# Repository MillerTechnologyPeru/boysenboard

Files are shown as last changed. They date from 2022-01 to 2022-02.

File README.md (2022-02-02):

# BoysenBoard
Linux capable single board computer using the F1C200s in an Arduino form-factor.

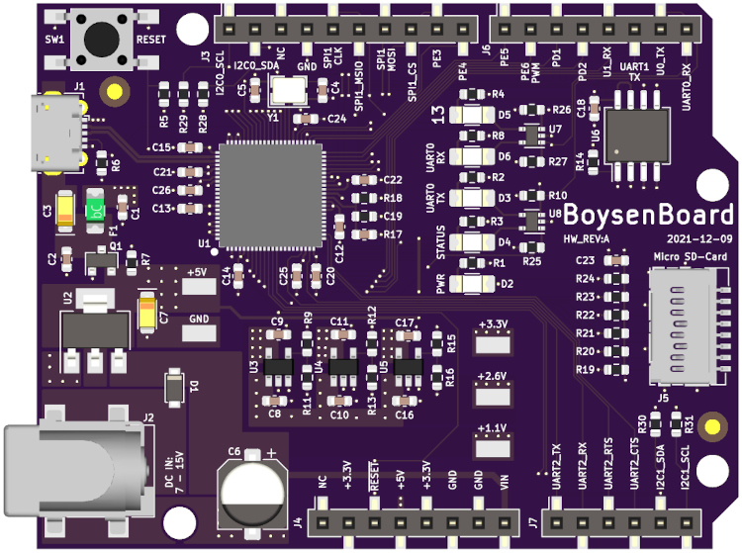
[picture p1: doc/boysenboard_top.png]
BoysenBoard Top


## Build
The BoysenBoard supports booting from the on-board 16MB of SPI flash or from a 
Micro-SD card. The board will first try to boot from the SD card. If that 
fails, it will try the SPI flash. Otherwise it will enter FEL bootloader mode. 

### Setting up the Buildroot Environment
Clone this repo:
```
git clone https://github.com/mclewell/boysenboard
git submodule update --init
```
Change to the Buildroot directory:
```
cd boysenboard/software/buildroot
```

### Building the SPI Flash Image
We will be doing an out-of-tree build. Make an directory for the output:
```
mkdir output-spi
cd output-spi
```
Set-up the build:
```
make -C ../ O=$(pwd) BR2_EXTERNAL=$PWD/../../ boysenboard_spi_defconfig
```
Start the build (on my Ryzen 3900X this took about 7mins):
```
make
```
Once complete, the resulting flash image will be at:
```
images/flash.bin
```
To flash images into the SPI flash, the board must be in FEL mode. If the SPI 
flash is blank, the board will automatically enter FEL mode. If a valid boot 
image already exists in the flash, the board can be placed into FEL mode using
a special SD-Card image.
```
wget https://github.com/linux-sunxi/sunxi-tools/raw/master/bin/fel-sdboot.sunxi
dd if=fel-sdboot.sunxi of=/dev/sdX bs=1024 seek=8
```
Note: ensure the board is fully powered down. Sometimes external USB-UART cables
will back-power the board.

Insert the FEL SD-Card and connect the USB cable. FEL mode can be verified by 
using ```lsusb```:
```
Bus 005 Device 010: ID 1f3a:efe8 Allwinner Technology sunxi SoC OTG connector in FEL/flashing mode
```
Start the flashing process with:
```
sudo host/bin/sunxi-fel -p spiflash-write 0 images/flash.bin
```
This process will take about 3mins. Once complete, remove the USB cable and 
SD-Card. Connect to the serial console on UART0 to see console output messages.

The first boot after flashing a new image will take a while as U-Boot sets up 
the UBIFS. Subsequent boots will be much fast. You will see the following 
messages from U-Boot while this occurs:
```
...
SF: Detected w25q128 with page size 256 Bytes, erase size 64 KiB, total 16 MiB
ubi0: attaching mtd2
ubi0: scanning is finished
ubi0: attached mtd2 (name "rootubi", size 15 MiB)
ubi0: PEB size: 65536 bytes (64 KiB), LEB size: 65408 bytes
ubi0: min./max. I/O unit sizes: 1/256, sub-page size 1
ubi0: VID header offset: 64 (aligned 64), data offset: 128
ubi0: good PEBs: 252, bad PEBs: 0, corrupted PEBs: 0
ubi0: user volume: 5, internal volumes: 1, max. volumes count: 128
ubi0: max/mean erase counter: 0/0, WL threshold: 4096, image sequence number: 1562368489
ubi0: available PEBs: 12, total reserved PEBs: 240, PEBs reserved for bad PEB handling: 0
...
```

Once booted, the login information is:
```
User: root
Password: [none]
```
The SPI flash image also sets the board up as a USB Gadget presenting the host
computer with a serial COM port device and USB mass storage. The serial port
typically enumerates as /dev/ttyACM0. 

### Building the SD Card Image
Like the SPI image,  we will be doing an out-of-tree build. Make an directory 
for the output:
```
mkdir output-sd
cd output-sd
```
Set-up the build:
```
make -C ../ O=$(pwd) BR2_EXTERNAL=$PWD/../../ boysenboard_sd_defconfig
```
Start the build (on my Ryzen 3900X this took about 7mins):
```
make
```
Once complete, the resulting SD-Card image will be at:
```
images/sdcard.img
```
Write the image to an SD-Card:
```
sudo dd if=image/sdcard.img of=/dev/sdX bs=1M status=progress && sync
```
Note: the SD-Card image does not enable the USB Gadget feature.

# Acknowledgements
This project is derived from [George Hillard's busiesscard-linux](https://github.com/thirtythreeforty/businesscard-linux)
project. 

Also thanks to [Icenowy](https://github.com/Icenowy) for their work getting U-Boot and Linux running
on the F1C100s and F1C200s processors.

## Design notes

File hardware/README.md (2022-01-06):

# Known Issues
- Silk swapped for R17 and C19
- Alignment holes for J1 are too small
- Add paste aperatures for SD-Card socket (J5)
- Add paste aperatures for GND hole pads on USB connector (J1)
- Add buffers on UART0 (my external tools are back-powering through the F1C200s 
ESD diodes)
- Remove UART0 RX/TX from LEDs and replace with other GPIO (LEDs are always on 
and 115200 baud is too fast for any meaningful blinking)
- Button or jumper to enter FEL Mode by holding SPI0_CS low.

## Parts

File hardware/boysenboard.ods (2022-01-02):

# | References | Value | QTY | Manufacturer | PartNumber | Supplier | SupplierPartNumber
1 | C4 C5 | 30pF | 2 | YAGEO | CC0603JRNPO9BN300 | Digi-Key | 311-3357-1-ND
2 | C1 C2 C13 C14 C15 C18 C19 C21 C22 C23 C25 C26 | 0.1uF | 12 | Samsung Electro-Mechanics | CL10B104KB8NNNL | Digi-Key | 1276-CL10B104KB8NNNLCT-ND
3 | C8 C9 C10 C11 C12 C16 C17 C20 C24 | 1uF | 9 | Samsung Electro-Mechanics | CL10B105KA8NFNC | Digi-Key | 1276-1942-1-ND
4 | C3 C7 | 10uF | 2 | KYOCERA AVX | TAJA106K016SNJ | Digi-Key | 478-8875-1-ND
5 | C6 | 47uF | 1 | Wurth Elektronik | 875105344006 | Digi-Key | 732-6421-1-ND
6 | D1 | DSS16UTR | 1 | SMC Diode Solutions | DSS16UTR | Digi-Key | 1655-1929-1-ND
7 | D2 D3 D4 D5 D6 | GRN | 5 | Wurth Elektronik | 150120VS75000 | Digi-Key | 732-4993-1-ND
8 | F1 | 500mA | 1 | Eaton - Electronics Division | PTS120615V050 | Digi-Key | 283-3140-1-ND
9 | J1 | 1050171001 | 1 | Molex | 1050171001 | Digi-Key | WM11262CT-ND
10 | J2 | 54-00164 | 1 | Tensility International Corp | 54-00164 | Digi-Key | 839-54-00164CT-ND
11 | J5 | Micro-SD | 1 | Molex | 1051620001 | Digi-Key | WM14405CT-ND
12 | J7 | NPTC061KFXC-RC | 1 | Sullins Connector Solutions | NPTC061KFXC-RC | Digi-Key | S5598-ND
13 | J4 J6 | NPTC081KFXC-RC | 2 | Sullins Connector Solutions | NPTC081KFXC-RC | Digi-Key | S5600-ND
14 | J3 | NPTC101KFXC-RC | 1 | Sullins Connector Solutions | NPTC101KFXC-RC | Digi-Key | S5602-ND
15 | Q1 | BSS308PEH6327XTSA1 | 1 | Infineon Technologies | BSS308PEH6327XTSA1 | Digi-Key | BSS308PEH6327XTSA1CT-ND
16 | R2 R3 R4 R8 | 261 | 4 | Stackpole Electronics Inc | RMCF0603FT261R | Digi-Key | RMCF0603FT261RTR-ND
17 | R1 | 604 | 1 | Stackpole Electronics Inc | RMCF0603FT604R | Digi-Key | RMCF0603FT604RCT-ND
18 | R17 R18 | 2.2K | 2 | Stackpole Electronics Inc | RMCF0603FT2K20 | Digi-Key | RMCF0603FT2K20CT-ND‎
19 | R28 R29 R30 R31 | 4.7K | 4 | Stackpole Electronics Inc | RMCF0603FT4K70 | Digi-Key | RMCF0603FT4K70DKR-ND
20 | R7 R14 R19 R20 R21 R22 R23 R24 | 10K | 8 | Stackpole Electronics Inc | RMCF0603FT10K0 | Digi-Key | RMCF0603FT10K0TR-ND
21 | R9 | 17.8K | 1 | Stackpole Electronics Inc | RMCF0603FG17K8 | Digi-Key | RMCF0603FG17K8CT-ND
22 | R5 R6 R10 R11 R13 R16 R25 R26 R27 | 47K | 9 | Stackpole Electronics Inc | RMCF0603FT47K0 | Digi-Key | RMCF0603FT47K0TR-ND
23 | R12 | 105K | 1 | Stackpole Electronics Inc | RMCF0603FT105K | Digi-Key | RMCF0603FT105KCT-ND
24 | R15 | 147K | 1 | Stackpole Electronics Inc | RMCF0603FT147K | Digi-Key | RMCF0603FT147KCT-ND
25 | SW1 | PTS645SL70SMTR92LFS | 1 | C&K | PTS645SL70SMTR92LFS | Digi-Key | CKN10820CT-ND
26 | U3 U4 U5 | AP7366-W5-7 | 3 | Diodes Incorporated | AP7366-W5-7 | Digi-Key | AP7366-W5-7DICT-ND
27 | U7 U8 | DMN32D2LDF | 2 | Diodes Incorporated | DMN32D2LDF-7 | Digi-Key | DMN32D2LDF-7DICT-ND
28 | U1 | F1C200s | 1 | Allwinner | F1C200s | SuperBuy | F1C200s
29 | U2 | LM1117-5.0 | 1 | Texas Instruments | LM1117MPX-5.0 | Digi-Key | LM1117MPX-5.0CT-ND
30 | U6 | W25Q128JVSIQ | 1 | Winbond Electronics | W25Q128JVSIQ | Digi-Key | W25Q128JVSIQ-ND
31 | Y1 | 24MHz | 1 | ECS Inc. | ECS-240-20-33-TR3 | Digi-Key | 50-ECS-240-20-33-TR3CT-ND

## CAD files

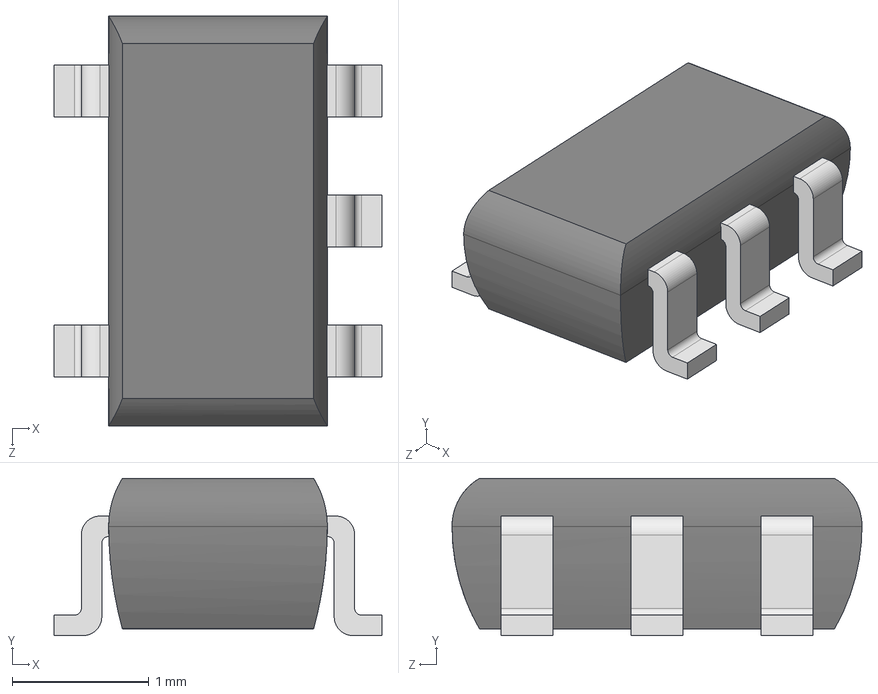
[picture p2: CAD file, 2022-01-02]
hardware/models/User Library-sot25.step
2.40 x 1.15 x 3.00 mm

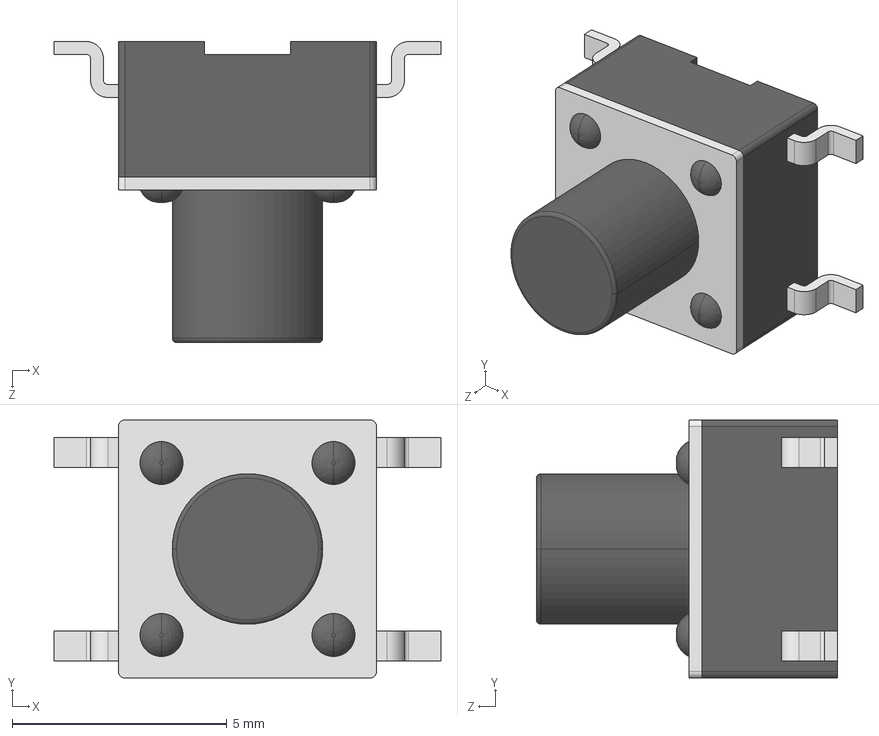
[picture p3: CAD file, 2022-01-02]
hardware/models/User Library-PTS645SL70SMTR92-LFS.STEP
9.00 x 6.00 x 7.00 mm

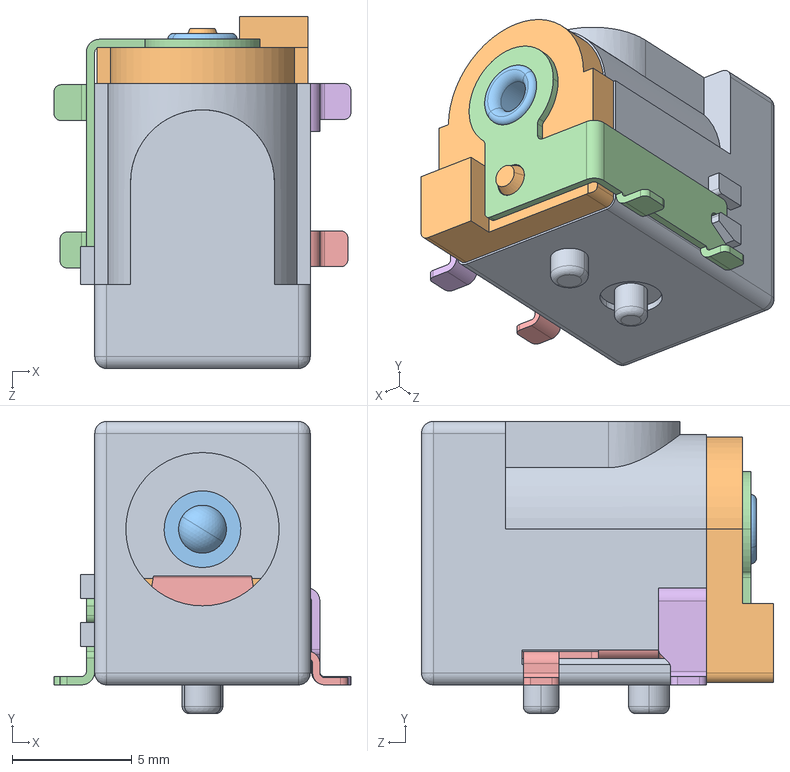
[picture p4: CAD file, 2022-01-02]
hardware/models/54-00164.STEP
12.4 x 12.2 x 14.7 mm
54-00164_shell
54-00164_insulator
54-00164_center
54-00164_center contact
54-00164_spring contact
54-00164_shell contact

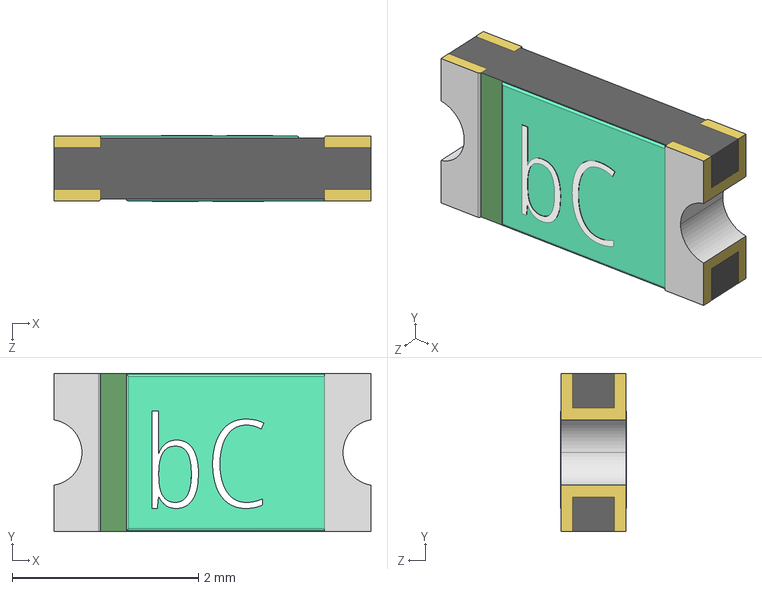
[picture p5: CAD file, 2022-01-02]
hardware/models/User Library-0ZCJ0005FF2E.step
3.40 x 1.70 x 0.708 mm

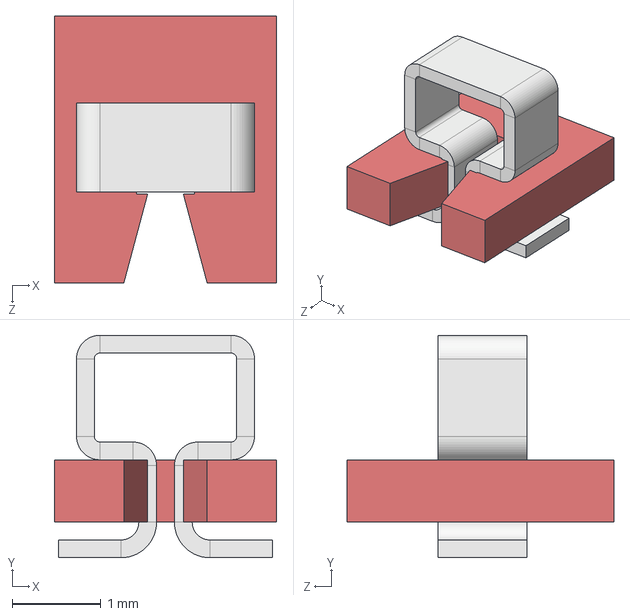
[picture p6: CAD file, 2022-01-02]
hardware/models/keystone-PN5190TR.STEP
2.50 x 2.50 x 3.00 mm
5190_insulation
5190_assembled contact

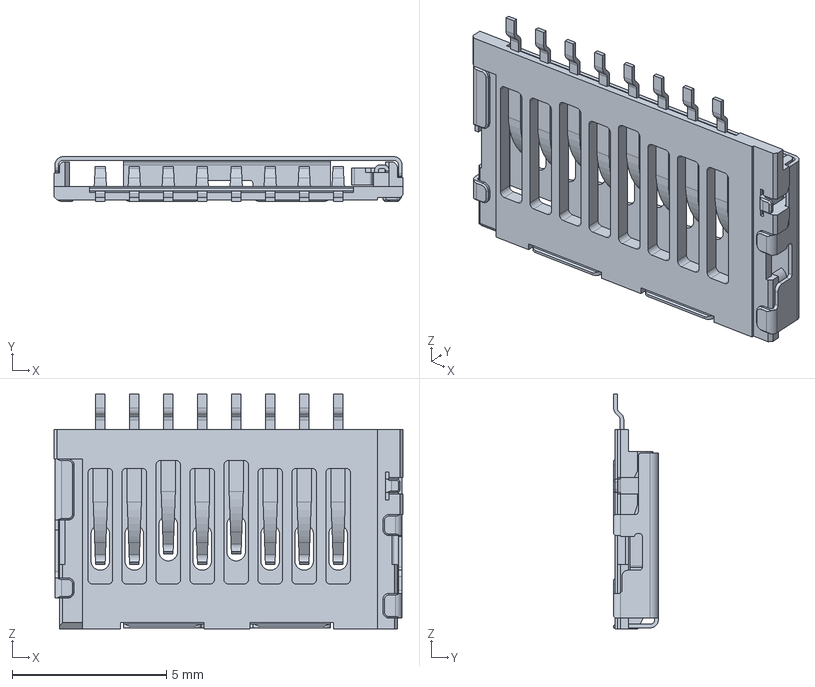
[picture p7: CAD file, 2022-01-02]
hardware/models/1051620001.stp
11.3 x 1.45 x 7.60 mm

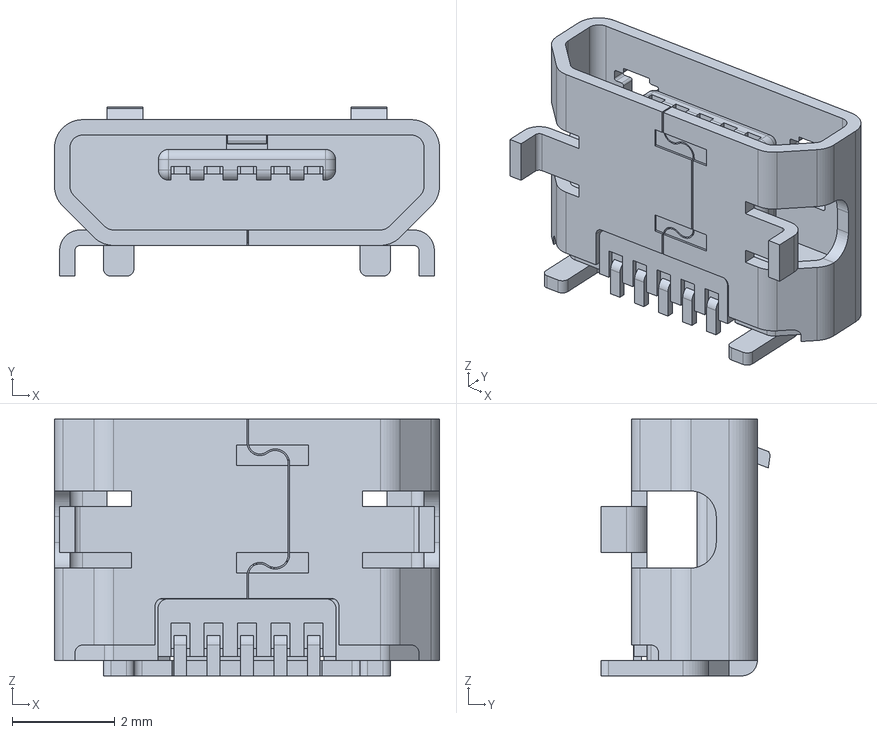
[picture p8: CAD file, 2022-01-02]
hardware/models/1050171001.stp
7.50 x 3.30 x 5.00 mm

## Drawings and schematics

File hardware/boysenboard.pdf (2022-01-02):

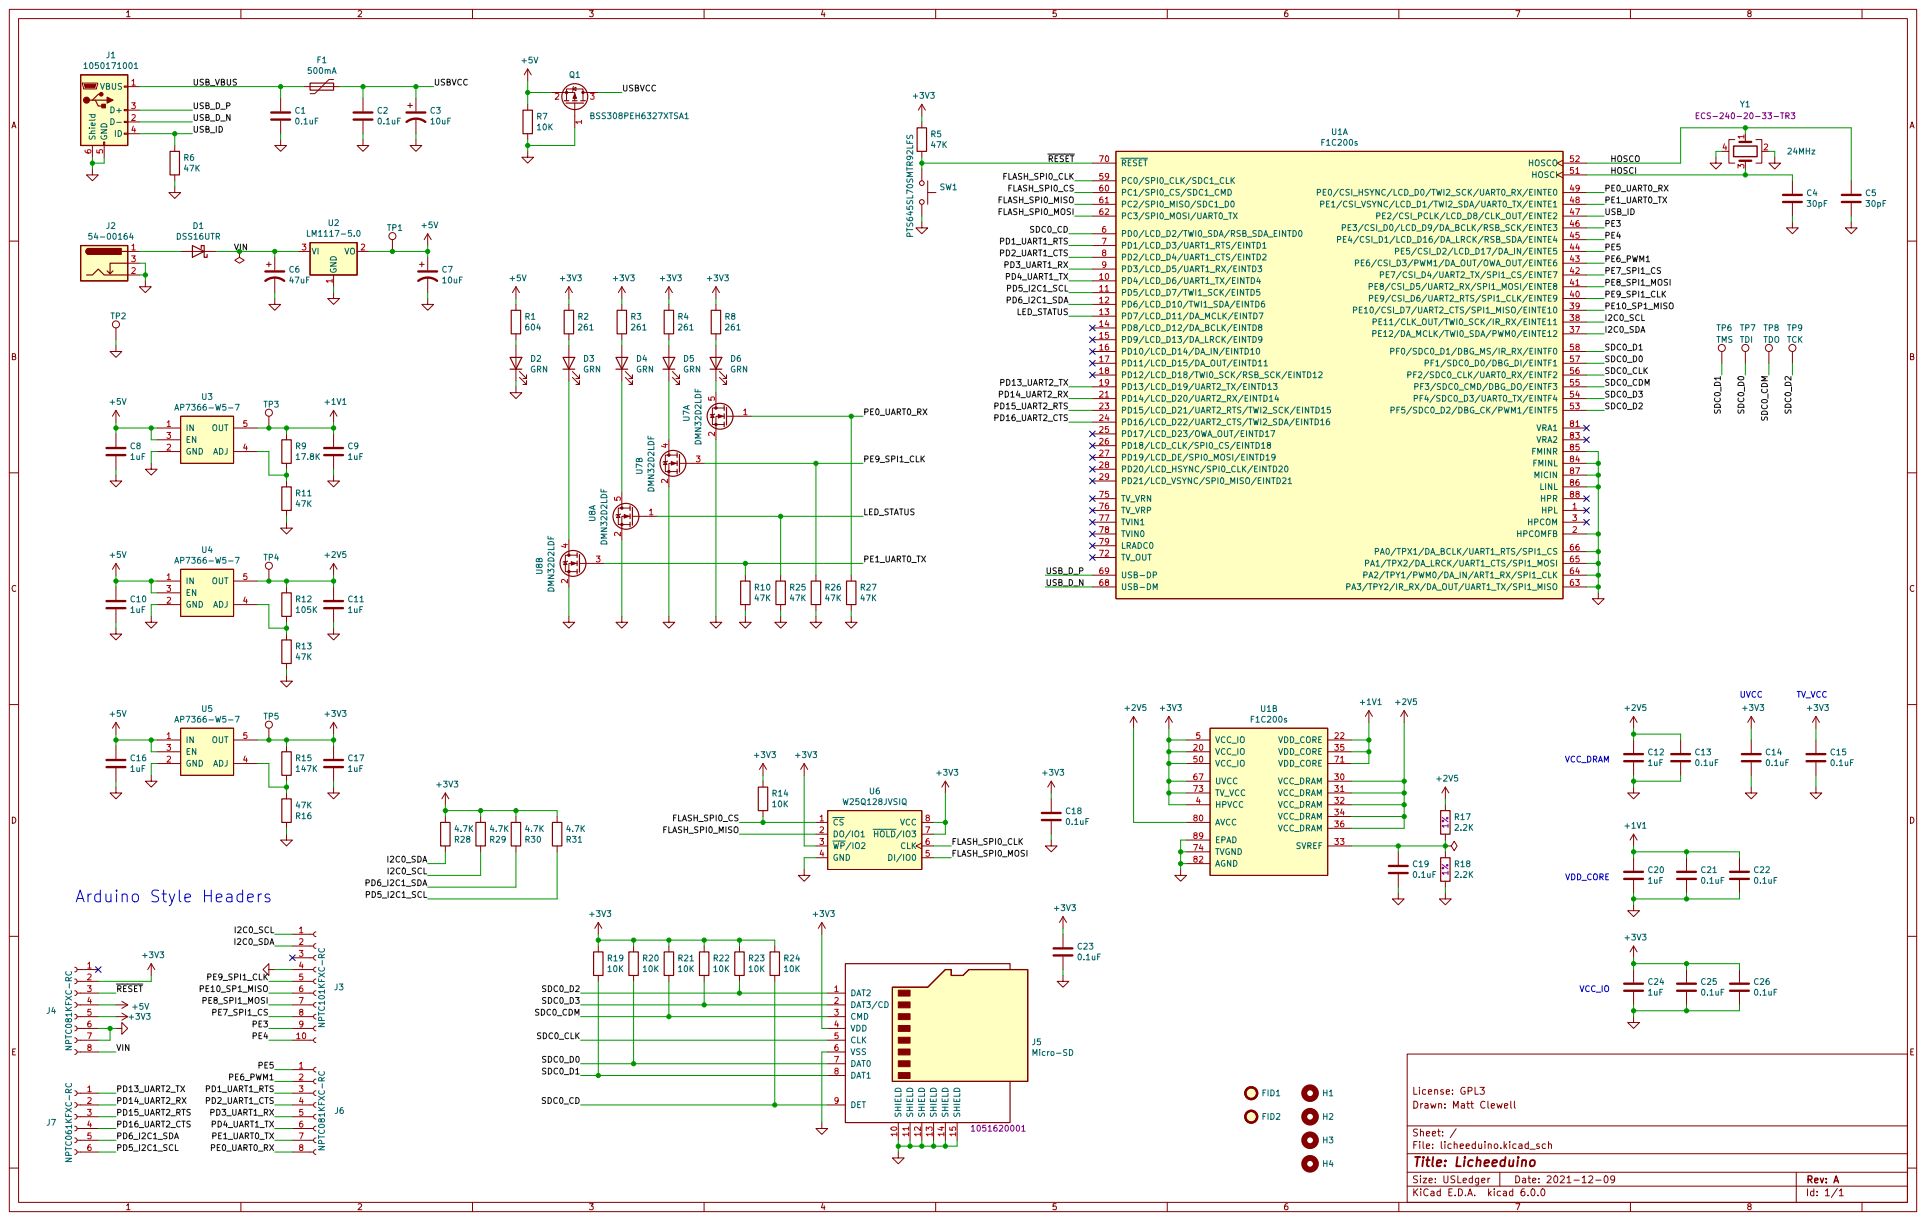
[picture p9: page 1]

File: licheeduino.kicad_sch Sheet: / Drawn: Matt Clewell License: GPL3

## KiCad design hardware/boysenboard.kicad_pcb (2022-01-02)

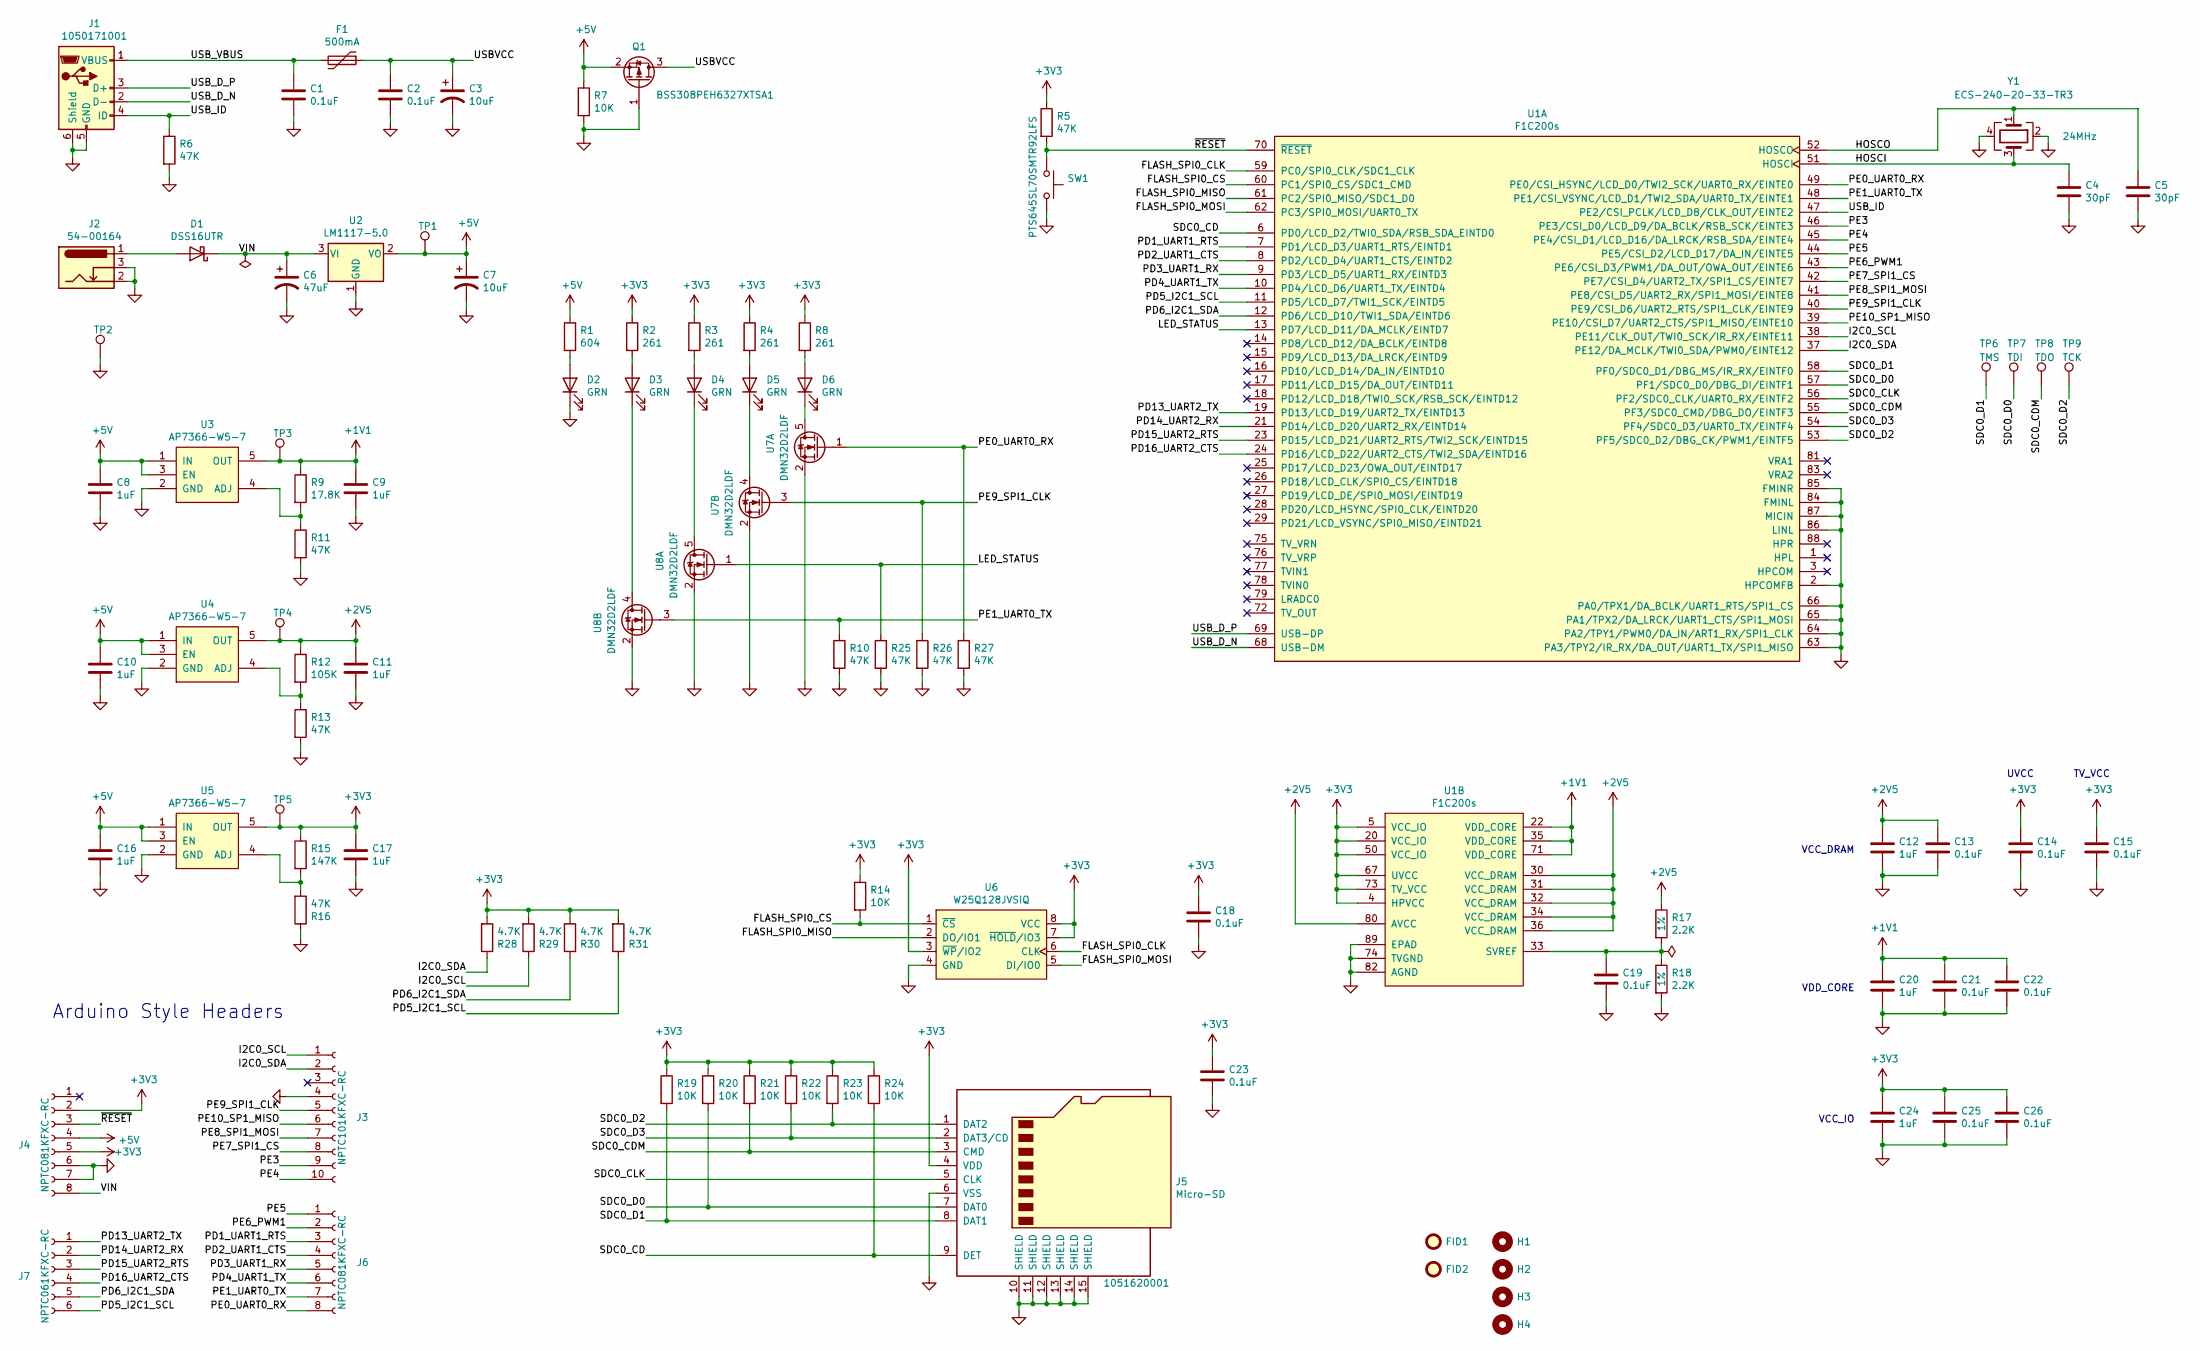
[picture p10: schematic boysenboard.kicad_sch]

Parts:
C1, C2, C13, C14, C15, C18, C19, C21, C22, C23, C25, C26: 0.1uF; C_0603_1608Metric; PartNumber CL10B104KB8NNNL
C3, C7: 10uF; CP_EIA-3216-18_Kemet-A; PartNumber TAJA106K016SNJ
C4, C5: 30pF; C_0603_1608Metric; PartNumber CC0603JRNPO9BN300
C6: 47uF; CP_Elec_6.3x5.8; PartNumber 875105344006
C8, C9, C10, C11, C12, C16, C17, C20, C24: 1uF; C_0603_1608Metric; PartNumber CL10B105KA8NFNC
D1: DSS16UTR; D_SOD-123F; PartNumber DSS16UTR
D2, D3, D4, D5, D6: GRN; LED_1206_3216Metric_Castellated; PartNumber 150120VS75000
F1: 500mA; Fuse_1206_3216Metric_Castellated; PartNumber PTS120615V050
FID1, FID2: Fiducial; Fiducial_1.5mm_Mask3mm
H1, H2, H3, H4: MountingHole; mounting_hole_125mil
J1: 1050171001; USB_Micro-B_Molex-105017-0001; PartNumber 1050171001
J2: 54-00164; barrel_jack_2.1mm; PartNumber 54-00164
J3: NPTC101KFXC-RC; PinSocket_1x10_P2.54mm_Vertical_SMD_Pin1Right; PartNumber NPTC101KFXC-RC
J4, J6: NPTC081KFXC-RC; PinSocket_1x08_P2.54mm_Vertical_SMD_Pin1Right; PartNumber NPTC081KFXC-RC
J5: Micro-SD; micro-sd; PartNumber 1051620001
J7: NPTC061KFXC-RC; PinSocket_1x06_P2.54mm_Vertical_SMD_Pin1Right; PartNumber NPTC061KFXC-RC
Q1: BSS308PEH6327XTSA1; SOT-23; PartNumber BSS308PEH6327XTSA1
R1: 604; R_0603_1608Metric; PartNumber RMCF0603FT604R
R2, R3, R4, R8: 261; R_0603_1608Metric; PartNumber RMCF0603FT261R
R5, R6, R10, R11, R13, R16, R25, R26, R27: 47K; R_0603_1608Metric; PartNumber RMCF0603FT47K0
R7, R14, R19, R20, R21, R22, R23, R24: 10K; R_0603_1608Metric; PartNumber RMCF0603FT10K0
R9: 17.8K; R_0603_1608Metric; PartNumber RMCF0603FG17K8
R12: 105K; R_0603_1608Metric; PartNumber RMCF0603FT105K
R15: 147K; R_0603_1608Metric; PartNumber RMCF0603FT147K
R17, R18: 2.2K; R_0603_1608Metric; Tolerance 1%; PartNumber RMCF0603FT2K20
R28, R29, R30, R31: 4.7K; R_0603_1608Metric; PartNumber RMCF0603FT4K70
SW1: PTS645SL70SMTR92LFS; switch_tactile_6x6mm_smt; PartNumber PTS645SL70SMTR92LFS
TP1, TP2, TP3, TP4, TP5: TestPoint; test_point_RCSCTE
TP6: TMS; TestPoint_Pad_D1.0mm
TP7: TDI; TestPoint_Pad_D1.0mm
TP8: TDO; TestPoint_Pad_D1.0mm
TP9: TCK; TestPoint_Pad_D1.0mm
U1: F1C200s; QFN-88; PartNumber F1C200s
U2: LM1117-5.0; SOT-223-3_TabPin2; PartNumber LM1117MPX-5.0
U3, U4, U5: AP7366-W5-7; SOT-23-6; PartNumber AP7366-W5-7
U6: W25Q128JVSIQ; SO-8_5.3x6.2mm_P1.27mm; PartNumber W25Q128JVSIQ
U7, U8: DMN32D2LDF; SOT-353_SC-70-5; PartNumber DMN32D2LDF-7
Y1: 24MHz; Crystal_SMD_Abracon_ABM8G-4Pin_3.2x2.5mm; PartNumber ECS-240-20-33-TR3

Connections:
+1V1: C9.1, C20.1, C21.1, C22.1, R9.1, TP3.1, U1.22 (VDD_CORE), U1.35 (VDD_CORE), U1.71 (VDD_CORE), U3.5 (OUT)
+2V5: C11.1, C12.1, C13.1, R12.1, R17.1, TP4.1, U1.30 (VCC_DRAM), U1.31 (VCC_DRAM), U1.32 (VCC_DRAM), U1.34 (VCC_DRAM), U1.36 (VCC_DRAM), U1.80 (AVCC), U4.5 (OUT)
+3V3: C14.1, C15.1, C17.1, C18.1, C23.1, C24.1, C25.1, C26.1, J4.2, J4.5, J5.4 (VDD), R2.1, R3.1, R4.1, R5.1, R8.1, R14.1, R15.1, R19.1, R20.1, R21.1, R22.1, R23.1, R24.1, R28.2, R29.2, R30.2, R31.2, TP5.1, U1.4 (HPVCC), U1.5 (VCC_IO), U1.20 (VCC_IO), U1.50 (VCC_IO), U1.67 (UVCC), U1.73 (TV_VCC), U5.5 (OUT), U6.3 (~WP/IO2), U6.7 (~HOLD/IO3), U6.8 (VCC)
+5V: C7.1, C8.1, C10.1, C16.1, J4.4, Q1.2 (S), R1.1, R7.1, TP1.1, U2.2 (VO), U3.1 (IN), U3.3 (EN), U4.1 (IN), U4.3 (EN), U5.1 (IN), U5.3 (EN)
/FLASH_SPI0_CLK: U1.59 (PC0/SPI0_CLK/SDC1_CLK), U6.6 (CLK)
/FLASH_SPI0_CS: R14.2, U1.60 (PC1/SPI0_CS/SDC1_CMD), U6.1 (~CS)
/FLASH_SPI0_MISO: U1.61 (PC2/SPI0_MISO/SDC1_D0), U6.2 (DO/IO1)
/FLASH_SPI0_MOSI: U1.62 (PC3/SPI0_MOSI/UART0_TX), U6.5 (DI/IO0)
/HOSCI: C4.1, U1.51 (HOSCI), Y1.3
/HOSCO: C5.1, U1.52 (HOSCO), Y1.1
/I2C0_SCL: J3.1, R29.1, U1.38 (PE11/CLK_OUT/TWI0_SCK/IR_RX/EINTE11)
/I2C0_SDA: J3.2, R28.1, U1.37 (PE12/DA_MCLK/TWI0_SDA/PWM0/EINTE12)
/LED_STATUS: R25.1, U1.13 (PD7/LCD_D11/DA_MCLK/EINTD7), U8.1 (G1)
/PD1_UART1_RTS: J6.3, U1.7 (PD1/LCD_D3/UART1_RTS/EINTD1)
/PD2_UART1_CTS: J6.4, U1.8 (PD2/LCD_D4/UART1_CTS/EINTD2)
/PD3_UART1_RX: J6.5, U1.9 (PD3/LCD_D5/UART1_RX/EINTD3)
/PD4_UART1_TX: J6.6, U1.10 (PD4/LCD_D6/UART1_TX/EINTD4)
/PD5_I2C1_SCL: J7.6, R31.1, U1.11 (PD5/LCD_D7/TWI1_SCK/EINTD5)
/PD6_I2C1_SDA: J7.5, R30.1, U1.12 (PD6/LCD_D10/TWI1_SDA/EINTD6)
/PD13_UART2_TX: J7.1, U1.19 (PD13/LCD_D19/UART2_TX/EINTD13)
/PD14_UART2_RX: J7.2, U1.21 (PD14/LCD_D20/UART2_RX/EINTD14)
/PD15_UART2_RTS: J7.3, U1.23 (PD15/LCD_D21/UART2_RTS/TWI2_SCK/EINTD15)
/PD16_UART2_CTS: J7.4, U1.24 (PD16/LCD_D22/UART2_CTS/TWI2_SDA/EINTD16)
/PE0_UART0_RX: J6.8, R27.1, U1.49 (PE0/CSI_HSYNC/LCD_D0/TWI2_SCK/UART0_RX/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), U7.1 (G1)
/PE1_UART0_TX: J6.7, R10.1, U1.48 (PE1/CSI_VSYNC/LCD_D1/TWI2_SDA/UART0_TX/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), U8.3 (G2)
/PE3: J3.9, U1.46 (PE3/CSI_D0/LCD_D9/DA_BCLK/RSB_SCK/EINTE3)
/PE4: J3.10, U1.45 (PE4/CSI_D1/LCD_D16/DA_LRCK/RSB_SDA/EINT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)
/PE5: J6.1, U1.44 (PE5/CSI_D2/LCD_D17/DA_IN/EINTE5)
/PE6_PWM1: J6.2, U1.43 (PE6/CSI_D3/PWM1/DA_OUT/OWA_OUT/EINTE6)
/PE7_SPI1_CS: J3.8, U1.42 (PE7/CSI_D4/UART2_TX/SPI1_CS/EINTE7)
/PE8_SPI1_MOSI: J3.7, U1.41 (PE8/CSI_D5/UART2_RX/SPI1_MOSI/EINTE8)
/PE9_SPI1_CLK: J3.5, R26.1, U1.40 (PE9/CSI_D6/UART2_RTS/SPI1_CLK/EINTE9), U7.3 (G2)
/PE10_SP1_MISO: J3.6, U1.39 (PE10/CSI_D7/UART2_CTS/SPI1_MISO/EINTE10)
/SDC0_CD: J5.9 (DET), R24.2, U1.6 (PD0/LCD_D2/TWI0_SDA/RSB_SDA_EINTD0)
/SDC0_CDM: J5.3 (CMD), R21.2, TP8.1, U1.55 (PF3/SDC0_CMD/DBG_DO/EINTF3)
/SDC0_CLK: J5.5 (CLK), U1.56 (PF2/SDC0_CLK/UART0_RX/EINTF2)
/SDC0_D0: J5.7 (DAT0), R20.2, TP7.1, U1.57 (PF1/SDC0_D0/DBG_DI/EINTF1)
/SDC0_D1: J5.8 (DAT1), R19.2, TP6.1, U1.58 (PF0/SDC0_D1/DBG_MS/IR_RX/EINTF0)
/SDC0_D2: J5.1 (DAT2), R23.2, TP9.1, U1.53 (PF5/SDC0_D2/DBG_CK/PWM1/EINTF5)
/SDC0_D3: J5.2 (DAT3/CD), R22.2, U1.54 (PF4/SDC0_D3/UART0_TX/EINTF4)
/USBVCC: C2.1, C3.1, F1.1, Q1.3 (D)
/USB_D_N: J1.2 (D-), U1.68 (USB-DM)
/USB_D_P: J1.3 (D+), U1.69 (USB-DP)
/USB_ID: J1.4 (ID), R6.1, U1.47 (PE2/CSI_PCLK/LCD_D8/CLK_OUT/EINTE2)
/USB_VBUS: C1.1, F1.2, J1.1 (VBUS)
/VIN: C6.1, D1.1 (K), J4.8, U2.3 (VI)
/~RESET: J4.3, R5.2, SW1.1, U1.70 (~RESET)
GND: C1.2, C2.2, C3.2, C4.2, C5.2, C6.2, C7.2, C8.2, C9.2, C10.2, C11.2, C12.2, C13.2, C14.2, C15.2, C16.2, C17.2, C18.2, C19.2, C20.2, C21.2, C22.2, C23.2, C24.2, C25.2, C26.2, D2.1 (K), J1.5 (GND), J1.6 (Shield), J2.2, J2.3, J3.4, J4.6, J4.7, J5.6 (VSS), J5.10 (SHIELD), J5.11 (SHIELD), J5.12 (SHIELD), J5.13 (SHIELD), J5.14 (SHIELD), J5.15 (SHIELD), Q1.1 (G), R6.2, R7.2, R10.2, R11.2, R13.2, R16.1, R18.2, R25.2, R26.2, R27.2, SW1.2, TP2.1, U1.2 (HPCOMFB), U1.63 (PA3/TPY2/IR_RX/DA_OUT/UART1_TX/SPI1_MISO), U1.64 (PA2/TPY1/PWM0/DA_IN/ART1_RX/SPI1_CLK), U1.65 (PA1/TPX2/DA_LRCK/UART1_CTS/SPI1_MOSI), U1.66 (PA0/TPX1/DA_BCLK/UART1_RTS/SPI1_CS), U1.74 (TVGND), U1.82 (AGND), U1.84 (FMINL), U1.85 (FMINR), U1.86 (LINL), U1.87 (MICIN), U1.89 (EPAD), U2.1 (GND), U3.2 (GND), U4.2 (GND), U5.2 (GND), U6.4 (GND), U7.2 (S), U8.2 (S), Y1.2, Y1.4
unnamed: C19.1, R17.2, R18.1, U1.33 (SVREF)
unnamed: D1.2 (A), J2.1
unnamed: D2.2 (A), R1.2
unnamed: D3.1 (K), U8.4 (D2)
unnamed: D3.2 (A), R2.2
unnamed: D4.1 (K), U8.5 (D1)
unnamed: D4.2 (A), R3.2
unnamed: D5.1 (K), U7.4 (D2)
unnamed: D5.2 (A), R4.2
unnamed: D6.1 (K), U7.5 (D1)
unnamed: D6.2 (A), R8.2
unnamed: R9.2, R11.1, U3.4 (ADJ)
unnamed: R12.2, R13.1, U4.4 (ADJ)
unnamed: R15.2, R16.2, U5.4 (ADJ)

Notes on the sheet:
UVCC
TV_VCC
VDD_CORE
VCC_IO
Arduino Style Headers
VCC_DRAM

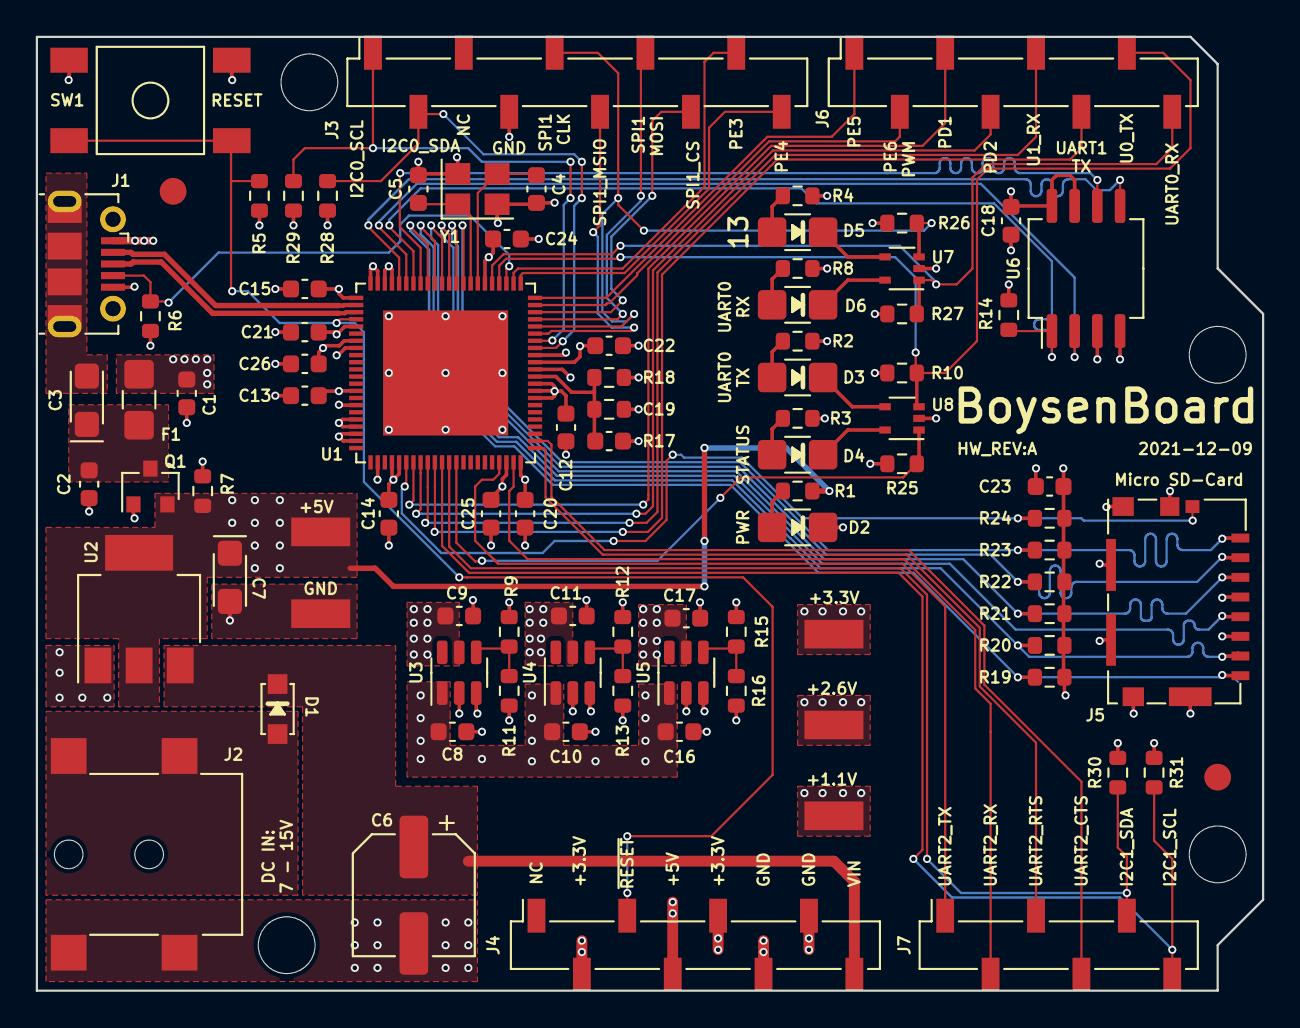
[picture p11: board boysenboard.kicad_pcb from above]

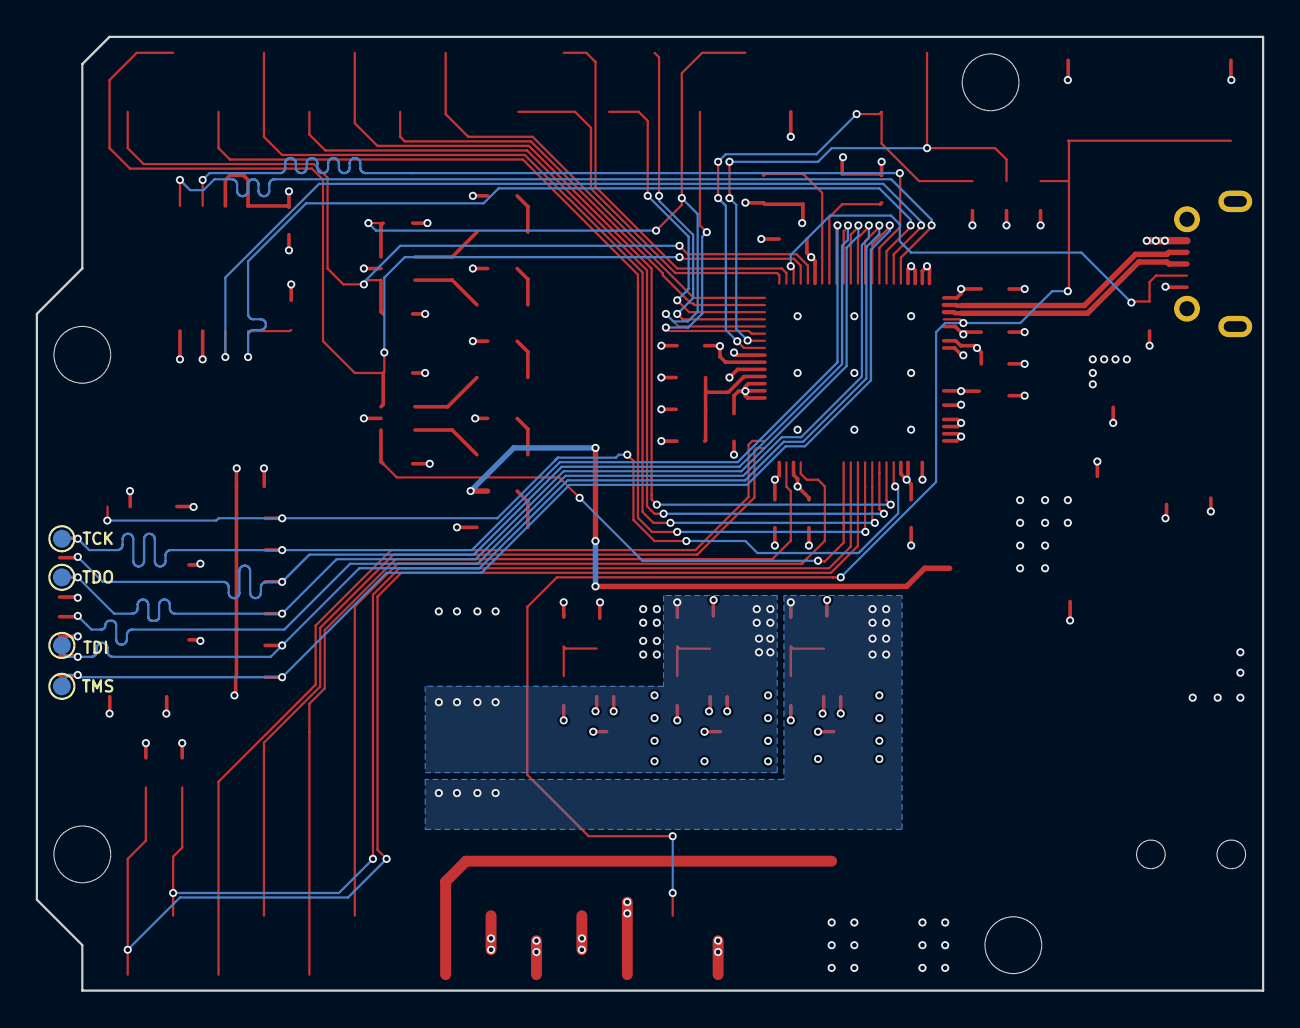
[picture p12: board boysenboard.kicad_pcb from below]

Board: 4 copper layers, 68.6 x 53.3 mm, 97 parts (4 on the bottom side), 62 nets.

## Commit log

2022-01-02 Fixed footprint references and kicad 5->6 models
    [boysenboard.kicad_pcb, boysenboard.kicad_sch]
2022-01-02 Fixed PCB DRC violations caused by Kicad 5->6 conversion
    [boysenboard.kicad_pcb]
